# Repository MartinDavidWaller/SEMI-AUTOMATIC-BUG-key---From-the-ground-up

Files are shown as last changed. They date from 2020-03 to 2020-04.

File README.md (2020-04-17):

# SEMI-AUTOMATIC BUG key - From the ground up

The details found here relate to a project published in Practical Wireless. 
It combines a 3d printed [Key](Key.md) and an Arduino based [Keyer](Keyer.md).

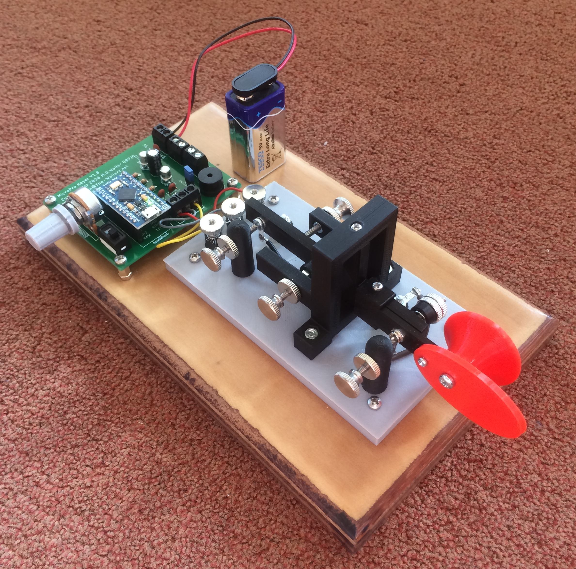
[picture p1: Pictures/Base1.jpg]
 
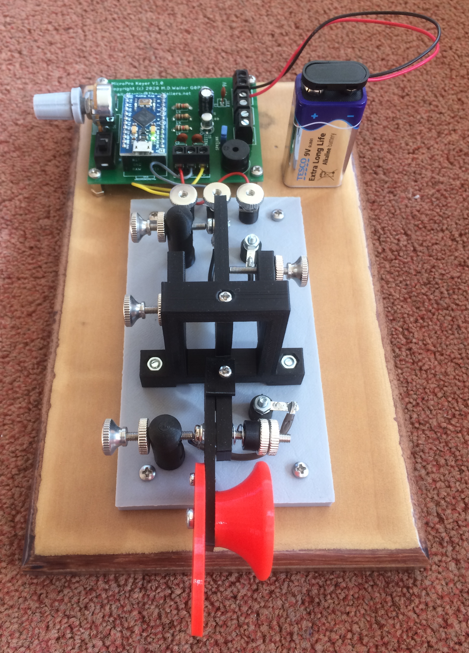
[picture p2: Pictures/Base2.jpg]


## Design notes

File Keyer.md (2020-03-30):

# SEMI-AUTOMATIC "BUG" key - From the ground up

Keyer
 
## Required Components
 
### Resistors
 
| Value | Quantity | Comment |
| --- | --- | --- |
| 1K | 3 | |
| 10K | 1 | |
| Linear Variable 10K | 1 | PCB mountable type |

### Capacitors
 
| Value | Quantity | Comment |
| --- | --- | --- |
| 0.01uF | 3 | |
| 100uF | 1 | Electrolytic, radial lead |

### Semiconductors
 
| Part | Quantity | Comment |
| --- | --- | --- |
| 2N2222 | 2 | |

### Miscellaneous

The URL links provided are not to be seen as any form of promotion, simply as guidance as to what the exact component is.
 
| Part | Quantity | Comment |
| --- | --- | --- |
| 6x6mm Tactile Switch | 1 | Similar to <https://www.bitsbox.co.uk/index.php?main_page=product_info&cPath=116_117_119&products_id=3263> | |
| Miniature PCB slide switch | 1 | Similar to <https://www.bitsbox.co.uk/index.php?main_page=product_info&cPath=116_120_124_125&products_id=870> |
| Miniature Electromagnetic Transducer | 1 | Similar to <https://www.bitsbox.co.uk/index.php?main_page=product_info&cPath=302_309&products_id=2098> |
| 2-Way PCB Terminal Blocks | 3 | Similar to <https://www.bitsbox.co.uk/index.php?main_page=product_info&cPath=225_232&products_id=2962> |
| 3-Way PCB Terminal Blocks | 1 | Similar <https://www.bitsbox.co.uk/index.php?main_page=product_info&cPath=225_232&products_id=1712> | 
| 12-Way SingleRow Socket | 2 | Optional, the Arduino can be soldered to the board. <https://www.bitsbox.co.uk/index.php?main_page=product_info&cPath=225_230&products_id=1643> |
| Arduino Pro Micro | 1 | Similar to <https://www.ebay.co.uk/itm/1-2-5-10PCS-Leonardo-Pro-Micro-ATmega32U4-16MHz-5V-ATmega328-Arduino-Pro-Mini/152216277704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> |
| PCB | 1 | Optional, the keyer can easily be built on Veroboard or similar. |

## Installing the Build Software

Start by installing the Arduino IDE. This can be found at:

https://www.arduino.cc/en/Main/Software

For the purpose of this build the Windows version Arduino 1.8.8 was used. 
All default installation options were accepted.

## Compiling the source code

- This project is based on the K3NG open source keyer and the code can be found here <https://github.com/k3ng/k3ng_cw_keyer>.
At the top right of this page you will see a green button that reads "Clone or download". Click on the small downward arrow and select "Download ZIP". 
Unzip the contents into a folder of your choice.
- To support the chosen hardware a few code changes need to be made. The table below details the file changes. 
It includes the filename, the old code and new code. Sadly line numbers are of little use as the K3NG project is evolving.

### Required Code Changes

The following two changes involve removing the "//" comment lead characters to enable the command button and speed potentiometer.
 
| File | Old Code | New Code |
| --- | --- | --- |
| keyer_features_and_options.h | // #define FEATURE_COMMAND_BUTTONS | #define FEATURE_COMMAND_BUTTONS |
| keyer_features_and_options.h | // #define FEATURE_POTENTIOMETER | #define FEATURE_POTENTIOMETER |

The following change involves changing the trailing 0 to 1 to have the speed potentiometer continually honoured.
 
| File | Old Code | New Code |
| --- | --- | --- |
| keyer_settings.h | #define potentiometer_always_on 0  | #define potentiometer_always_on 1 |

The following change involves changing the trailing 0 to 10 to assign the pin to be used to key the TX.
 
| File | Old Code | New Code |
| --- | --- | --- |
| keyer_pin_settings.h | #define ptt_tx_1 0 | #define ptt_tx_1 10 |

### Optional Code Changes

The following changes are optional. If you feel confident using the paddle, or simply up for a challenge, 
then these options can be changed by using the command button and the correct command as documented in the 
keyer wiki pages. If not so confident then it is probably worth doing the following:

The following change controls the startup keyer mode. It changes it from IAMBIC mode to BUG mode.

| File | Old Code | New Code |
| --- | --- | --- |
| k3ng_keyer.ino | configuration.keyer_mode = IAMBIC_B; | configuration.keyer_mode = BUG; |

The following three changes control the startup keyer speed and the upper and lower bounds of the speed
potentiometer.

| File | Old Code | New Code |
| --- | --- | --- |
| keyer_settings.h | #define initial_speed_wpm 26 | #define initial_speed_wpm 16 |
| keyer_settings.h | #define initial_pot_wpm_low_value 13  | #define initial_pot_wpm_low_value 8 |
| keyer_settings.h | #define initial_pot_wpm_high_value 35 | #define initial_pot_wpm_high_value 20 |

- Open the Arduino IDE and then open the k3ng_keyer.ino project file
- Navigate to Tools > Boards and select "Arduino Leonardo". Some of the Arduino Pro Micro devices seem to be identifying themselves as "LilyPad Arduino USB" devices. If
the one you have claims to be one of these then under Tools > Boards select the "LilyPad Arduino USB" device 
and not "Arduino Leonardo".
- Click the "Verify" button (Round circle with a tick mark in it - top left), if successful you will see something like 
"Sketch uses 20144 bytes (70%) of program storage space. Maximum is 28672 bytes.
Global variables use 825 bytes (32%) of dynamic memory, leaving 1735 bytes for local variables. Maximum is 2560 bytes."
though the number may not be exact.
- Make sure that the Arduino is plugged into your PC. Navigate to Tools > Port and make sure that the correct port is selected. See USB Issues below.
- Click the "Upload" button (Right pointing arrow - top left) to up load the software.
- The device should now be programmed correctly.

## PCB Revisions

- V1.1 - Legend changes.
- V1.0 - March 13th, 2020 - Initial board design.

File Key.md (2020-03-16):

# SEMI-AUTOMATIC "BUG" key - From the ground up

 Key
 
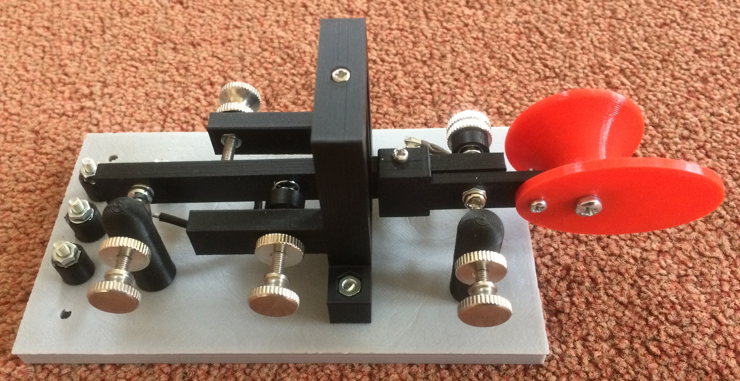
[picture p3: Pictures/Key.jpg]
  
 
 ## Required Parts
 
 The following parts are all 3D printed. The table below details the part, the colour, the infill, 
 and the approximate length of PLA required. If parts seem too 'bendy' then you may like to increase
 the infill percentage when printing.

| Part | Colour | Quantity | Infill % | Total Length |
| --- | ---| ---| --- | --- |
| Base | Grey | 1 | 20% | 8.56m |
| Binding Post	 | Black  | 5 | 20%	 | 0.55m |
| Dah Sprint Cup | Black  | 1 | 20%	 | 0.06m |
| Knob	 | Red | 1 | 20%	 | 1.23m |
| Knob Plate	 | Red | 1 | 20%	 | 0.28m |
| Lever Arm	 | Black  | 1 | 80%	 | 2.25m |
| Main Frame	 | Black  | 1 | 20%	 | 3.81m |
| Short Contact Post | Black  | 2 | 20%	 | 0.74m |
| Spring Cup	 | Black  | 1 | 20%	 | 0.08m |
| Yoke	 | BLack  | 1 | 80%	 | 0.82m |

Total length of PLA required 18.38m

The table below details all the additional hardware, nuts & bolts etc.

| Part | Quantity | See Note |
| --- | ---| --- |
| Compression Spring 7mm x 10mm | 2 | 1 |
| M2 Bolt 6mm | 1 | 2 |
| M2 Bolt 20mm | 3 | 3 |
| M2 Nut | 5 | 2 |
| M3 Bolt 6mm | 1 | 2 |
| M3 Bolt 12mm | 3 | 2 |
| M3 Bolt 16mm | 7 | 2 |
| M3 Bolt 25mm | 1 | 5 |
| M3 Knurled Bolt 20mm | 4 | 4 |
| M3 Knurled Nut | 6 | 4 |
| M3 Nut | 23 | 2 |
| M3 Nylon Washer | 1 | 2 |
| M3 Solder Tag | 15 | 2 |
| M3 Washer | 5 | 2 |

Notes:

1. Bought on ebay as a collection of assorted springs. Looking around you can find vendors selling individual prints. <https://www.ebay.co.uk/itm/Small-Tension-and-Compression-Springs-50-Mixed-Pack-Various-Sizes/362399846579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>
2. Bought from BitsBox. <https://www.bitsbox.co.uk/>
3. Bought on ebay. <https://www.ebay.co.uk/itm/A2-STAINLESS-STEEL-POZI-PAN-HEAD-MACHINE-SCREWS-POZIDRIVE-BOLTS-VARIOUS-SIZES-UK/111302864530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>
4. Bought on ebay. <https://www.ebay.co.uk/itm/Stainless-Steel-Knurled-Thumb-Screws-Hand-Grip-Knob-Bolts-M2-M2-5-M3-M4-M5-M6/283734090984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> <https://www.ebay.co.uk/itm/Carbon-Steel-Leveling-Round-Knurled-Thumb-Nut-Zinc-Ni-Plated-M2-M2-5-M3-M4-M5-M6/283734043425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>
5. Found in my bit box. I'm sure they will be readily found on ebay.

## Assembly

Assembly is quite easy. Below are the steps to follow. The only required tools are a screwdriver and small pliers.

### Step 1

Install 3 binding posts. These provide connections to the keyer. Each post requires:

* M3 Bolt 16mm * 1
* M3 Solder Tag * 1
* Printed Binding Post * 1
* M3 Nut * 2
* M3 Washer * 1

Expect to bury one nut within the body of the binding post. See the images below for the detailed construction. 

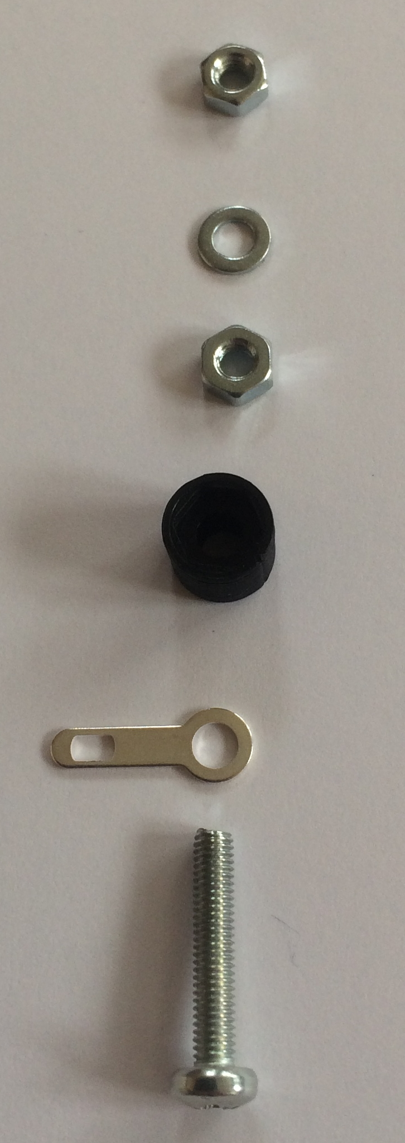
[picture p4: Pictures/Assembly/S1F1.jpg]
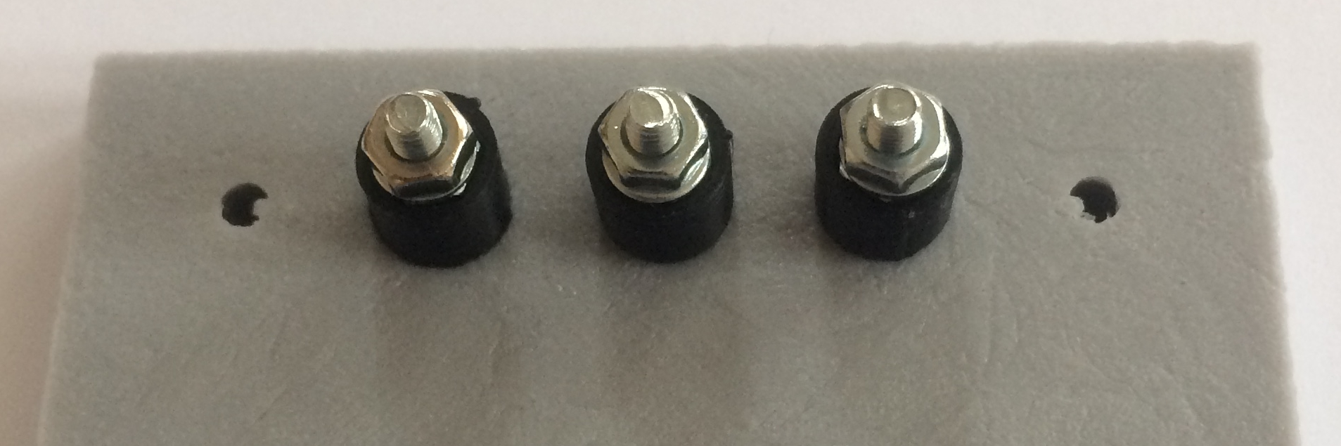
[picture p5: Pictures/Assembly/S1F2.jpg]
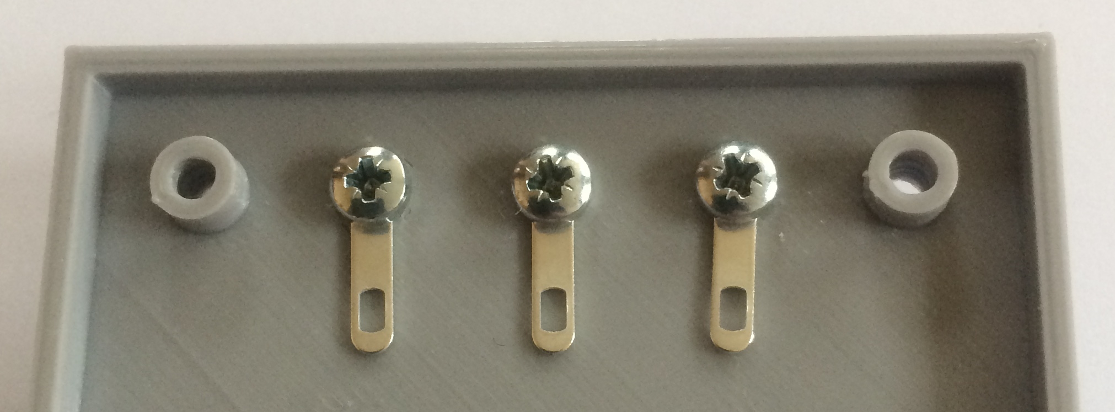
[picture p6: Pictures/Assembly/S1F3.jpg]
  

### Step 2

Install 2 binding posts. These provide connections to the DIT and DAH contacts. Each post requires:

* M3 Bolt 16mm * 1
* M3 Solder Tag * 2
* Printed Binding Post * 1
* M3 Nut * 2
* M3 Washer * 1

These are constructed in the same way as the binding posts in step 1 apart from there being an extra solder tag on the top side
of the board. See the images below for the detailed construction.

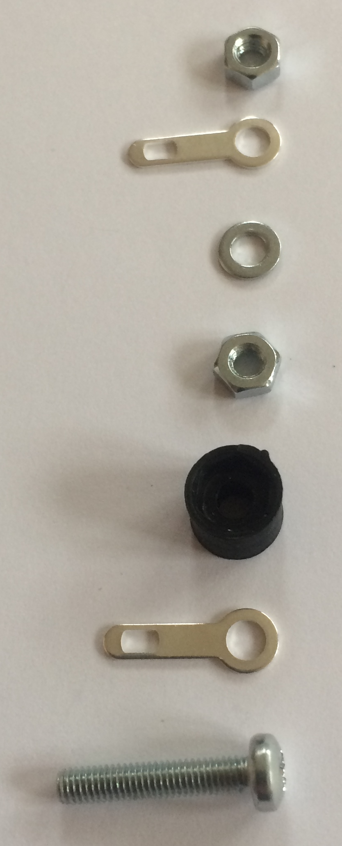
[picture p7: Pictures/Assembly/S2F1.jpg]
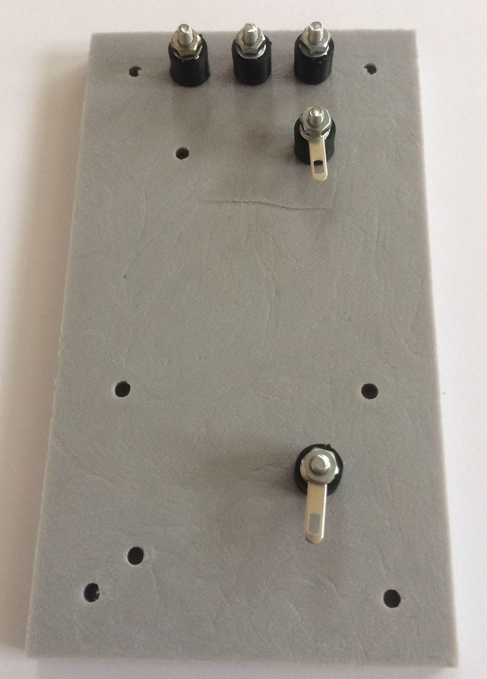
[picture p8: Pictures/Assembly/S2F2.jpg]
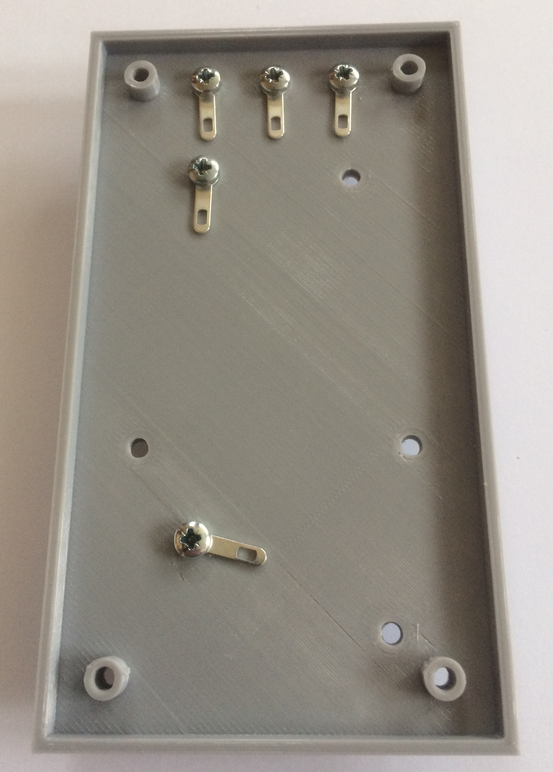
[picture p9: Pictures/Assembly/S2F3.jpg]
  

### Step 3

Install the knob and knob plate on the yoke. This requires:

* M2 Bolt 6mm * 1
* M2 Nut * 1
* M3 Bolt 12mm * 1
* M3 Nut * 1
* Printed Yoke * 1

Start by bolting the knob plate to the yoke using the M2 nut and bolt. The M2 nut should be buried in the yoke itself. 
Insert the M3 nut into the slot in the side of the knob and temporarily insert the M3 bolt in the bottom and screw home. 
This simply ensures that the nut is correctly positioned, remove the bolt. Push the M3 bolt through the knob plate, through
yoke, and into the knob. Position it so that the slot in the knob is pointing downwards and out of sight.
See the images below for the detailed construction.

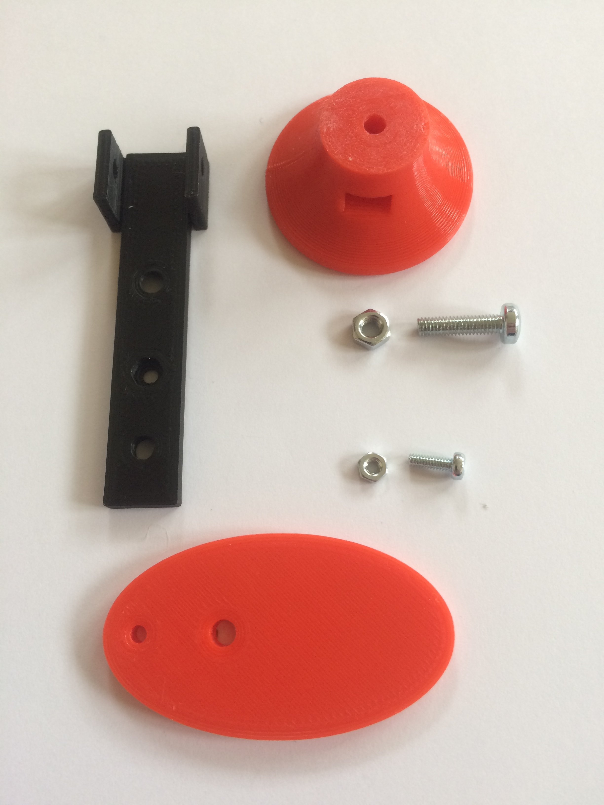
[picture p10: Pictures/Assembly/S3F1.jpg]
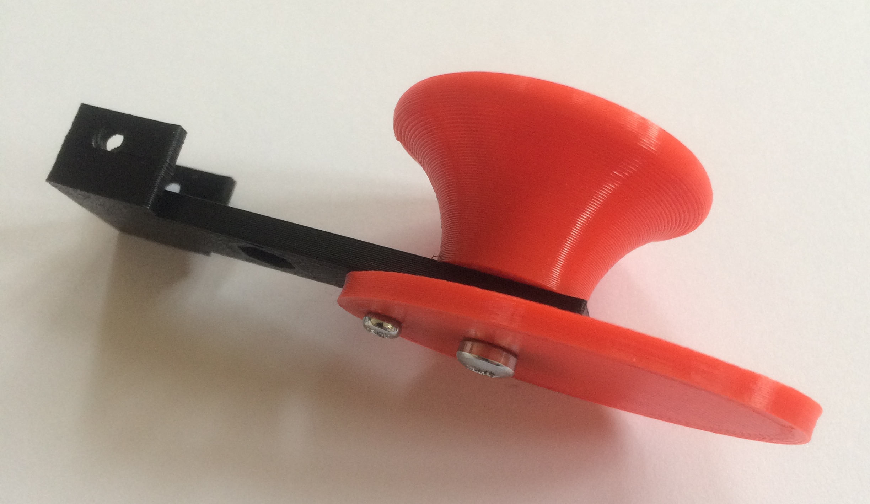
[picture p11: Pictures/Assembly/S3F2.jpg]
 

### Step 4

Install the DIT contact in the lever arm. This requires:

* M3 Bolt 6mm * 1
* M3 Nut * 1
* M3 Solder Tag * 1

Simply insert the bolt through the solder tab and then through the lever arm. The nut is buried in the lever arm itself.
See the images below for the detailed construction.

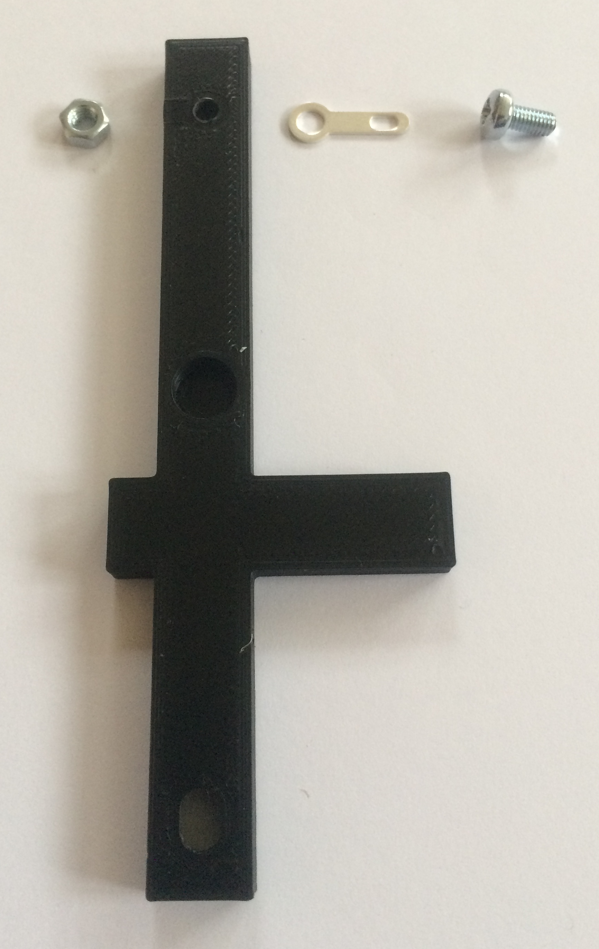
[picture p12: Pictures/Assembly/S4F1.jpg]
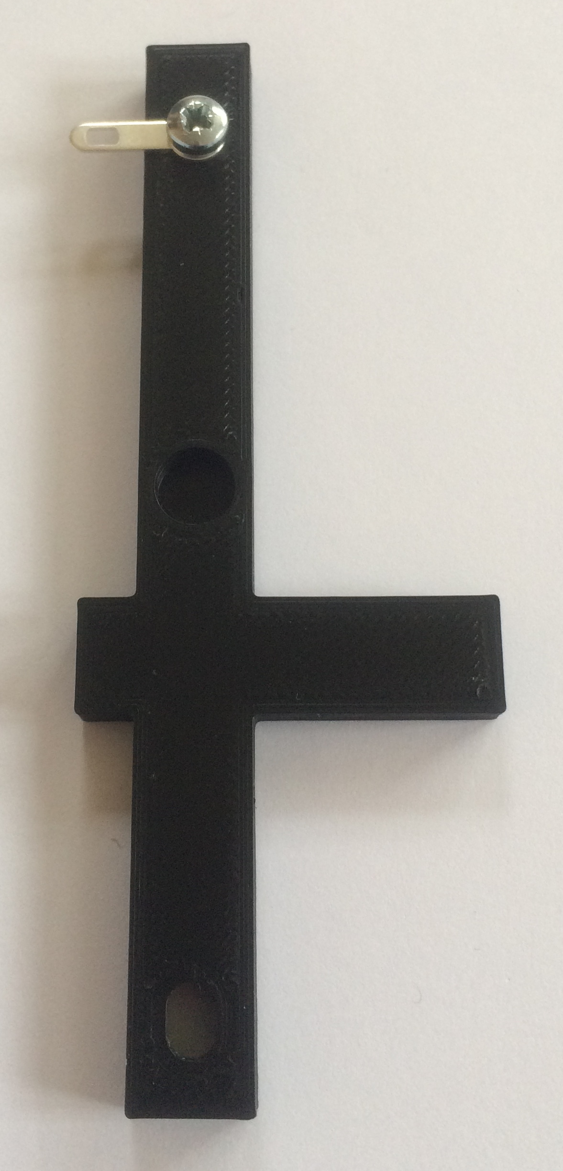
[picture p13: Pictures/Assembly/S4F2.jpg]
 

### Step 5

Assemble the DAH tension sprint. This requires:

* M3 Bolt 25mm * 1
* M3 Solder Tag * 1
* M3 Nut * 1
* M3 Nylon Washer * 1
* Compression Spring 7mm x 10mm * 1
* Assembled Lever Arm * 1
* Printed Dah Sprint Cup * 1
* M3 Knurled Nut * 2

Start by putting the solder tag on the M3 bolt, add the M3 nut and tightened all the way. Hold the lever arm on its side and
place the nylon washer between the yoke and the lever arm so that it aligns with the 3mm hole. Push the bolt through the
hole in the yoke, through the nylon washer and through the lever arm. Place the spring over the bolt followed by the
DAH sprint cup so that it holds the spring secure. Add the two remaining M3 knurled nuts. See the images below for the 
detailed construction.

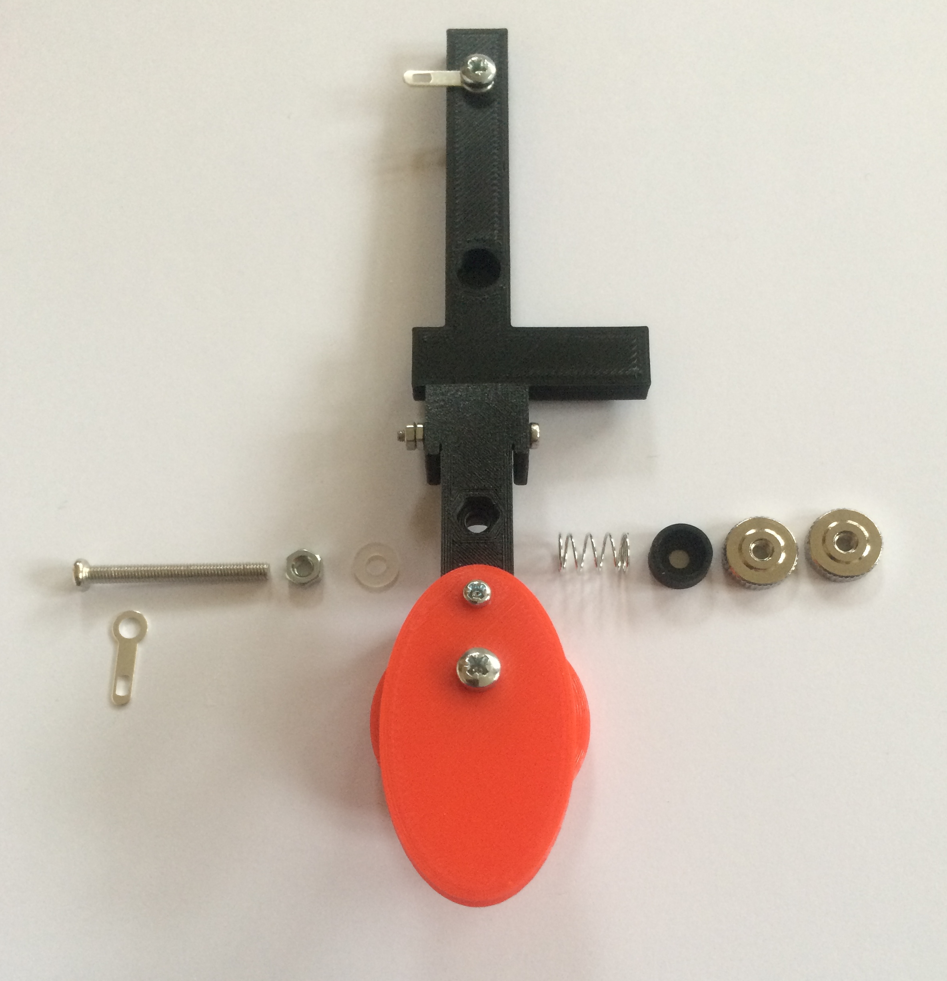
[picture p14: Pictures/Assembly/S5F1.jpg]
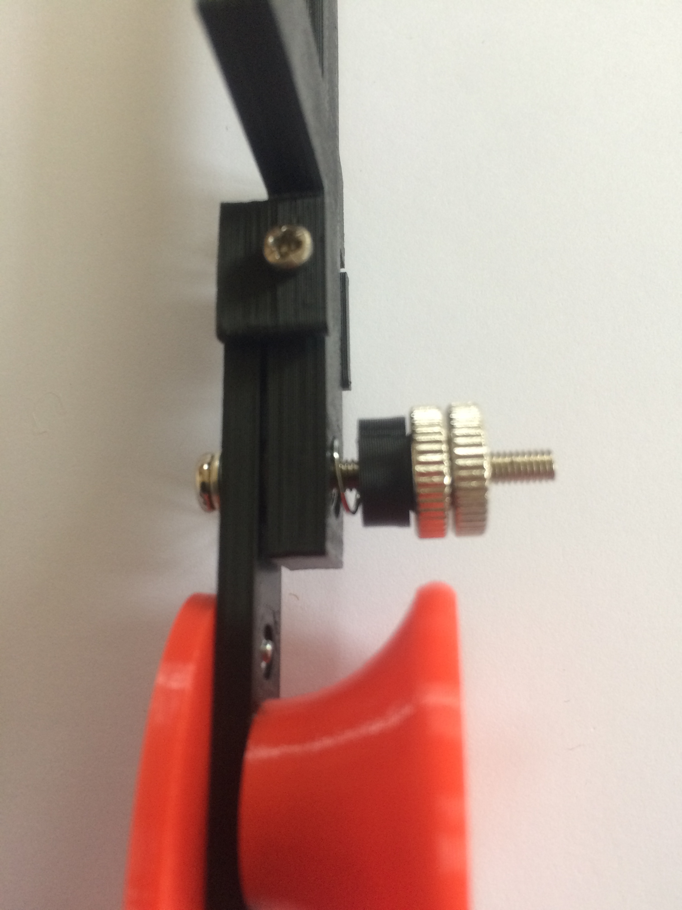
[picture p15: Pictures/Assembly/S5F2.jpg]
 

### Step 6

Assemble the DIT and DAH short contact posts. Each post requires:

* M3 Knurled Bolt 20mm * 1
* M3 Knulred Nut * 1
* M3 Solder Tag * 2
* M3 Nut * 2
* M3 Bolt 16mm * 1
* Printed Short Contact Post * 2

Starting at the top put the knurled nut onto the knurled bolt and screw it all the way down. 
Pass the bolt thought the 3mm hole in the side of the contact post and put one M3 solder 
tag and 3mm nut on the other size and screw home so that the nut is pulled into the contact 
post. At the bottom push the hoop end of a 3mm solder tag into the contact post and above 
that push in a M3 nut. Screw the M3 bolt up through the bottom until it has passed through
the nut. You should then be able to bend the bottom 3mm solder tag over the M3 nut so that 
it makes contact with the upper M3 solder tag. The solder tag can then be soldered together. 
This can be done in situ, but it is best to disassemble and solder them separately.
See the images below for the detailed construction.

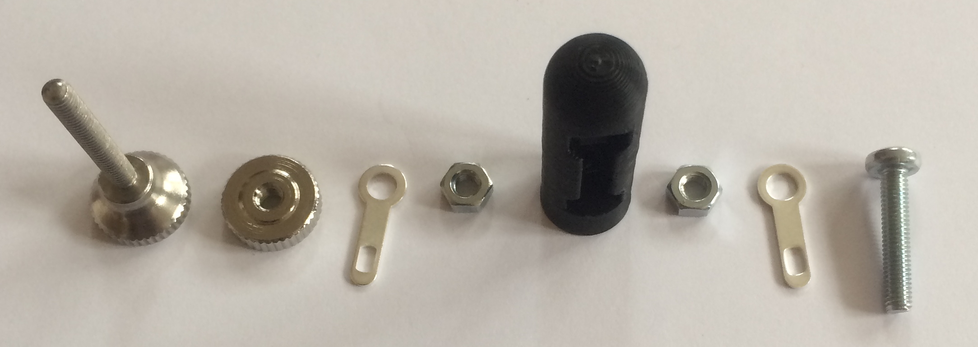
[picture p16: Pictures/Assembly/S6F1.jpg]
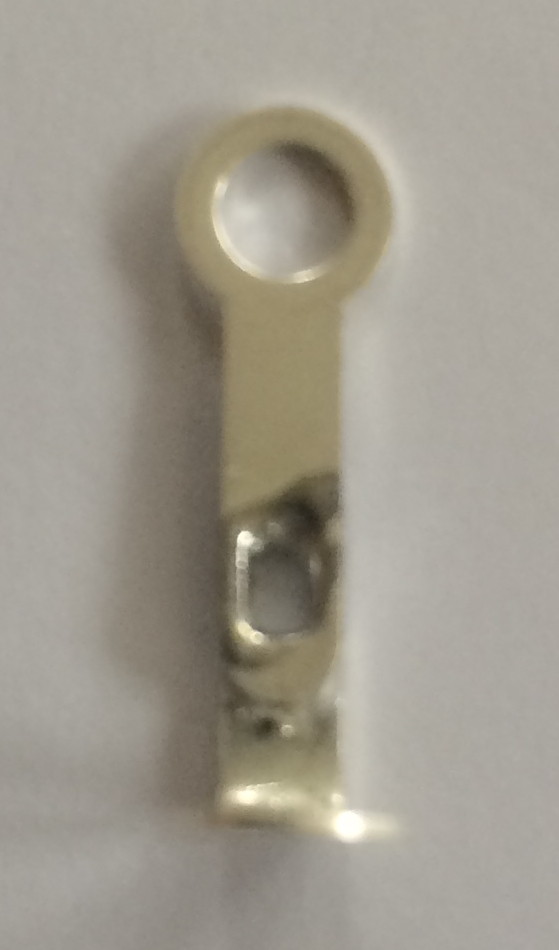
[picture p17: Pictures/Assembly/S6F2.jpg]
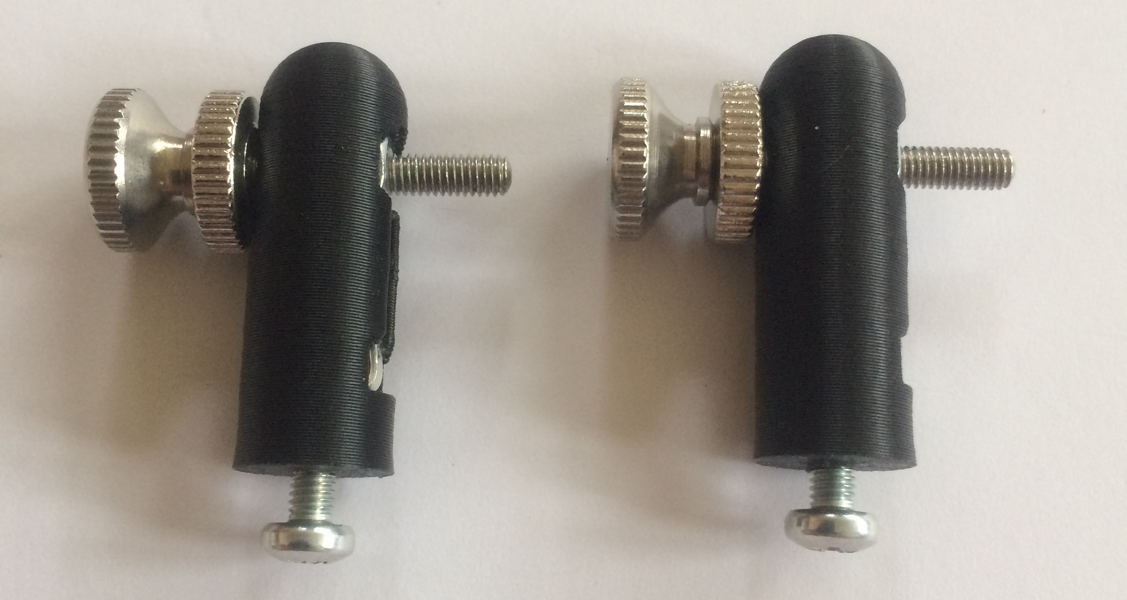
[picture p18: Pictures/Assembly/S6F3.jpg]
  

### Step 7

Assemble the DIT rest. This requires:

* M3 Knurled Bolt 20mm * 1
* M3 Knulred Nut * 1
* Printed Main Frame * 1

Put the 3mm knurled nut on to the 3mm knurled bolt and screw it halfway down. Push the end of the 
3mm bolt through the right-hand arm of the body and add the 3mm nut. Screw this home until the nut is
pulled into the arm. See the images below for the detailed construction.

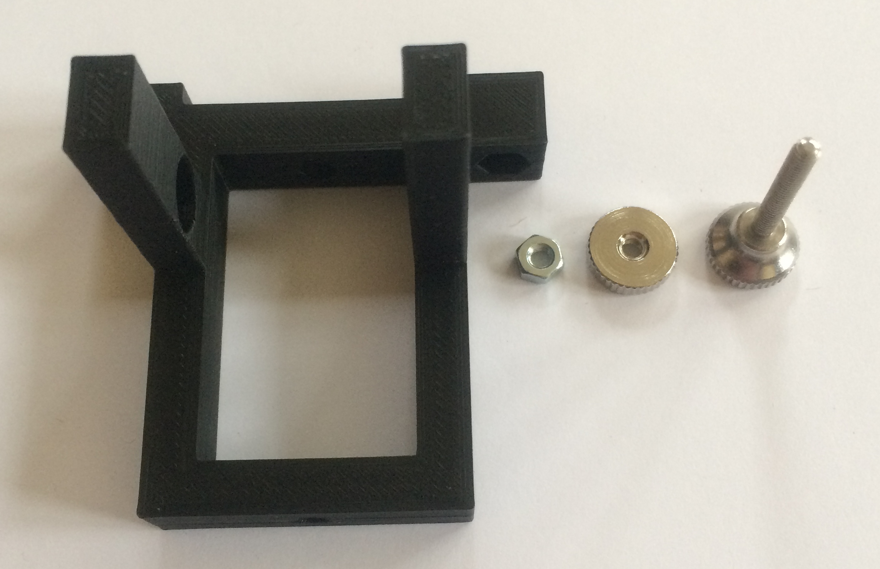
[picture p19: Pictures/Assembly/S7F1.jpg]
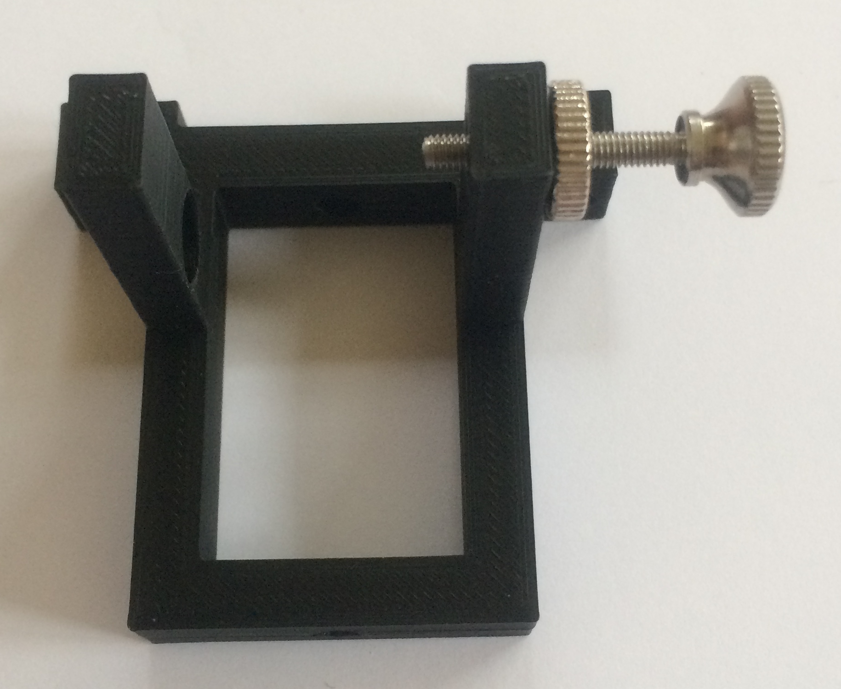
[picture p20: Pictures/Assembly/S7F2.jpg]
 

### Step 8

Assemble the DIT tension. This requires:

* M3 Knurled Bolt 20mm * 1
* M3 Knurled Nut * 1
* M3 Nut * 3
* Printed Spring Cup * 1
* Printed Main Frame * 1

Put the M3 knurled nut on to the M3 knurled bolt and screw it all the way down. Push the end of the 
3mm bolt through the left-hand arm of the body. Add two further M3 nuts, the sprint cup with the 
opening facing to the right, and a further M3 nut. The last two M3 nuts need to be adjusted to hold
the print cup tight at the end of the M3 knurled bolt. The inner M3 nut needs to be pulled into the
arm screwing home the bolt. See the images below for the detailed construction.

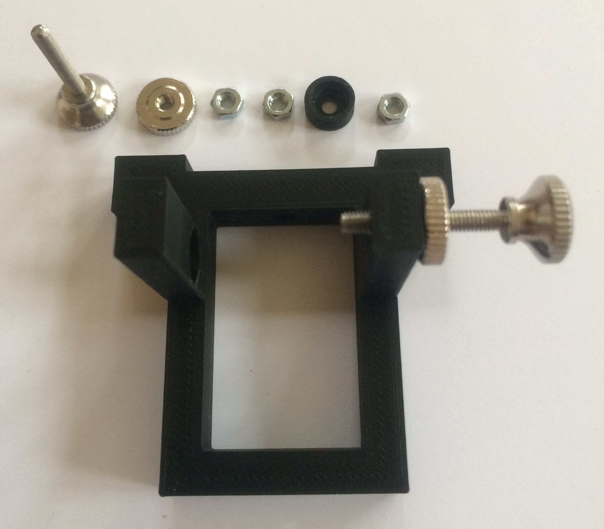
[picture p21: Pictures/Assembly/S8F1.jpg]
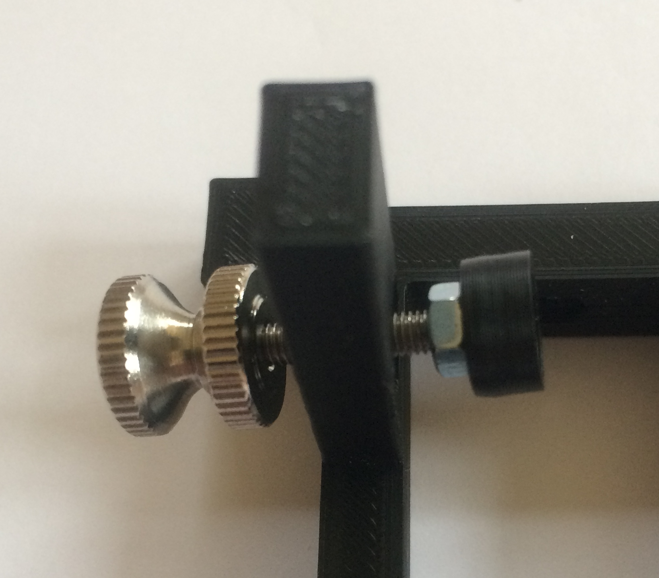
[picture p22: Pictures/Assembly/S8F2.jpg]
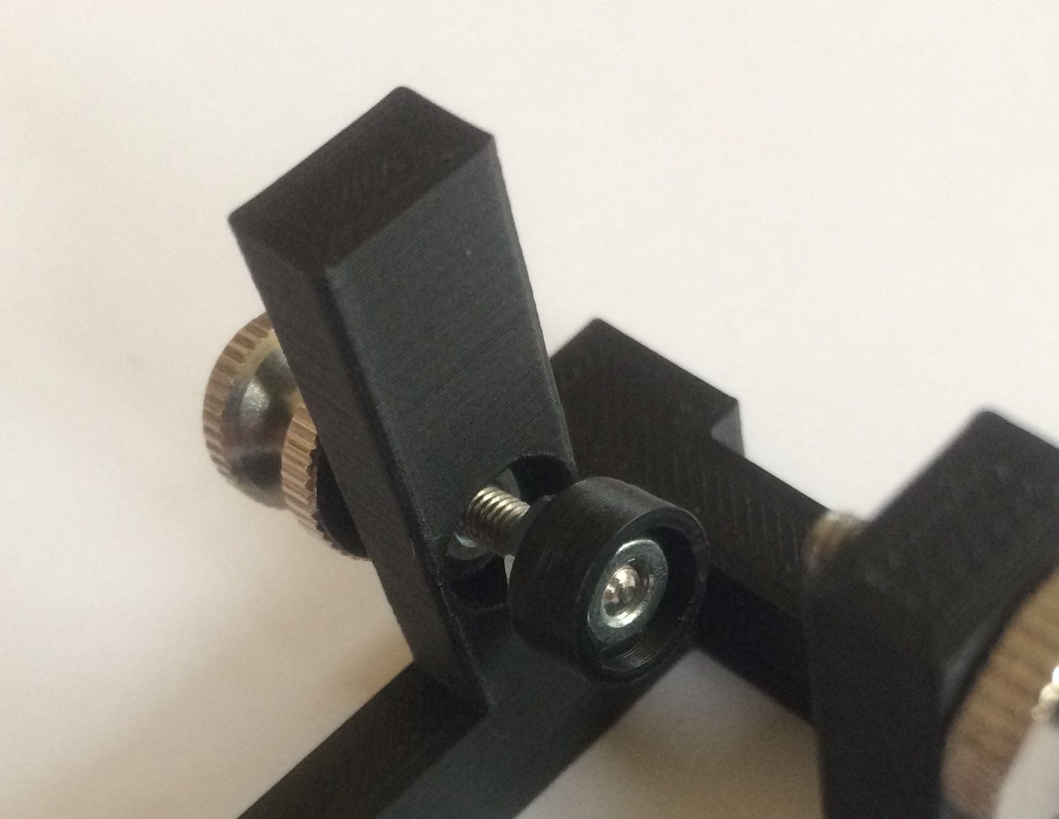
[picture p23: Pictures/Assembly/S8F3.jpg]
  

### Step 9

Secure the assembled lever arm into the body. This requires:

* Assembled lever arm * 1
* M2 Bolt 20mm * 2
* M2 Nut * 2
* Compression Spring 7mm x 10mm * 1
* Printed Main Frame * 1

Start by putting 1 M2 bolt though the top and screwing on a nut so that the thread just pokes though. Repeat this process for the
bottom. Push the assembled lever arm through the main frame until holes in the upright align with the M2 bolts. Screw the M2 bolts
home. This can be fiddly and best done holding the main frame horizontal. Put one end of the compression spring in the spring cup 
and the other end in the recess in the lever arm. You may need to adjust the DIT rest to hold the sprint in place. See the images 
below for the detailed construction.

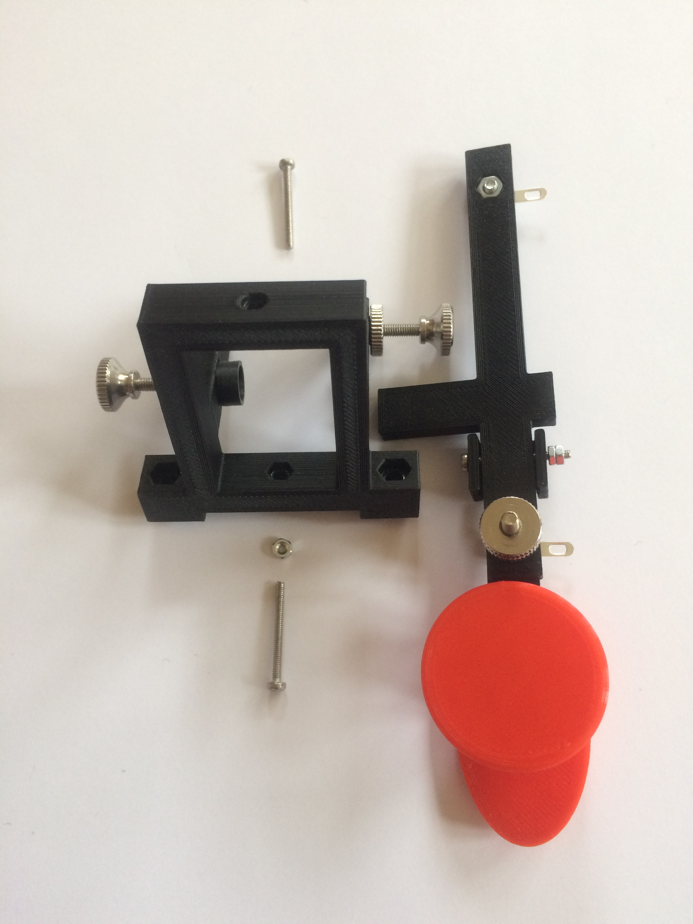
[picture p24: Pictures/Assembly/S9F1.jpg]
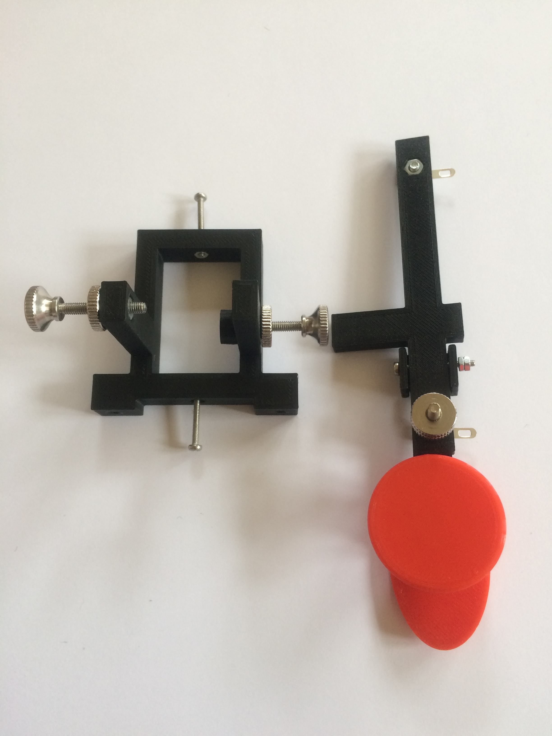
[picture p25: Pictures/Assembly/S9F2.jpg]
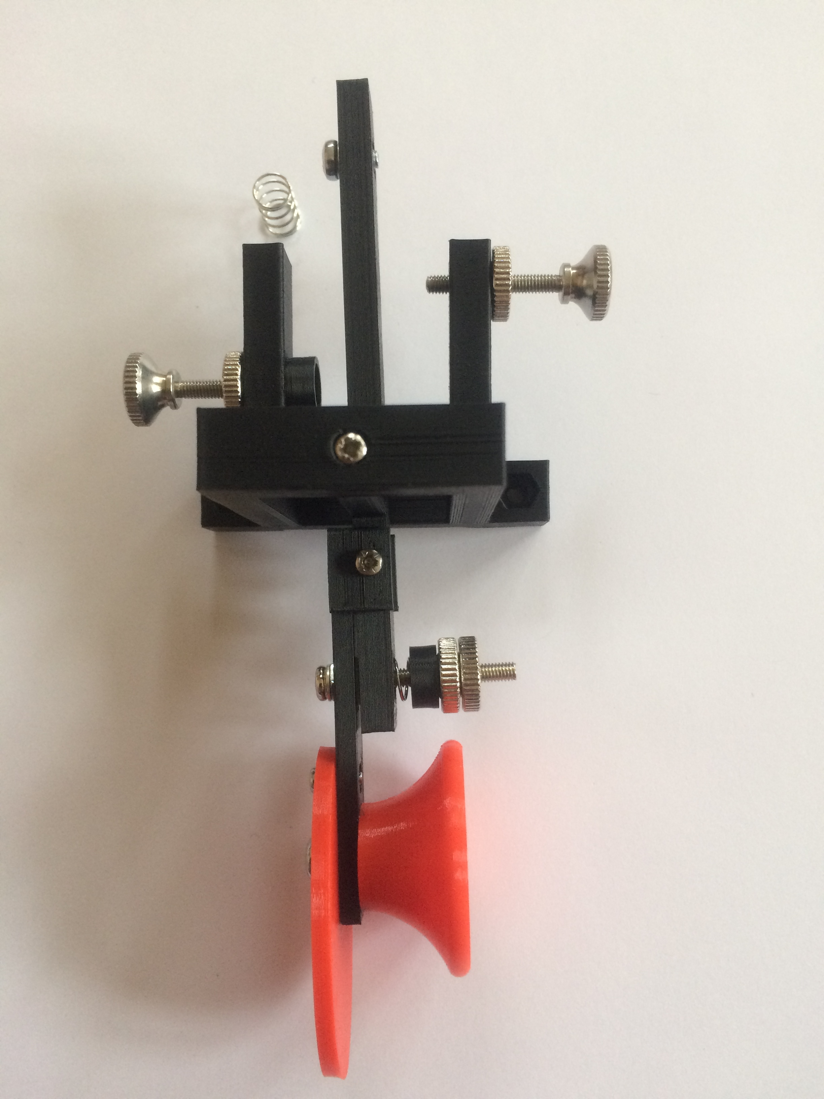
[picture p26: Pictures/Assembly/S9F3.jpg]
     

### Step 10

Secure the main frame to the base. This requires:

* M3 Bolt 16mm * 2
* M3 Nut * 2
* Assembled Base * 1
* Assembled Main Frame * 1

Insert the two M3 bolts up through the base and into the main frame. Add the M3 nuts and secure. See the images 
below for the detailed construction.

  

### Step 11

Secure the DIT and DAH contact posts to the base. This requires:

* M3 Solder Tag * 2
* Assembled Short Contact Post * 2
* Assembled Base * 1

Insert one M3 bolt through an M3 solder tag and then up through the base. Screw into the bottom of a sort contact post. 
Align the contact post with the associated DIT or DAH contact. Repeat for the second short contact post. See the images 
below for the detailed construction.

    

### Step 12

Add hook up wires. This requires:

* Assembled keyer * 1
* Short lengths of hook up wire, preferably multi strand for the top connections.

This is best described by the images below. 



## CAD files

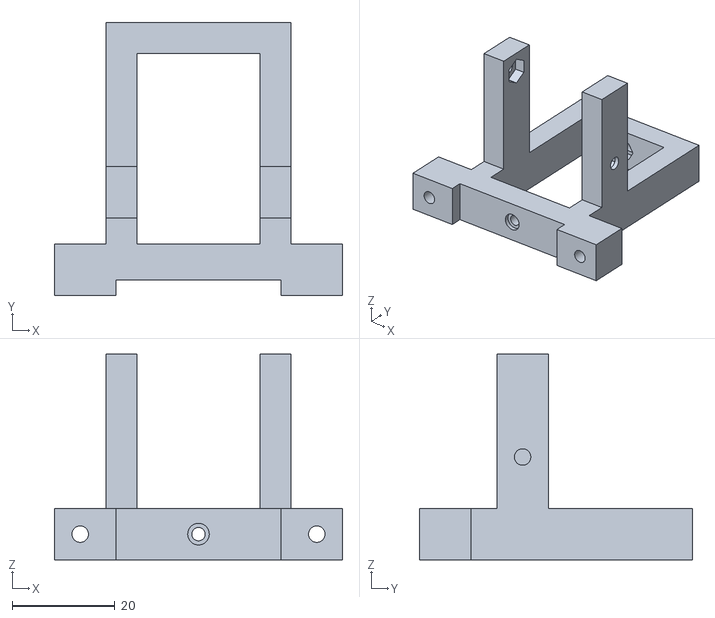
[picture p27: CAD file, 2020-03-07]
STL/MainFrame.stl
56.0 x 53.0 x 40.0

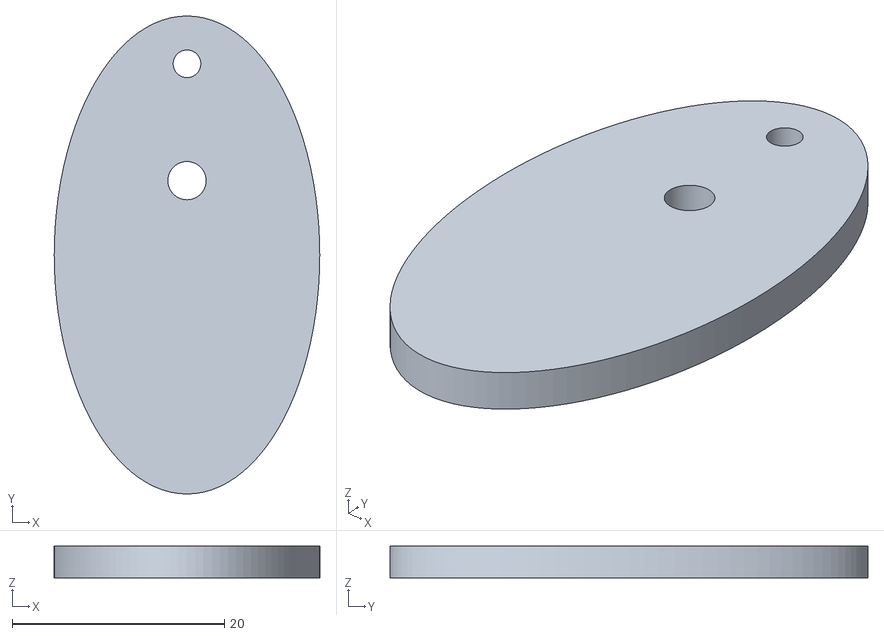
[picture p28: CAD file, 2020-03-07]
STL/KnobPlate.stl
25.0 x 45.0 x 3.00

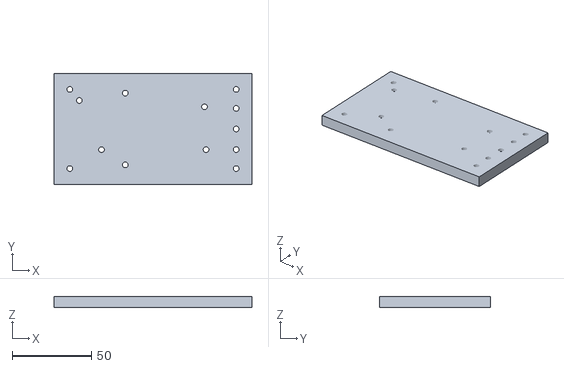
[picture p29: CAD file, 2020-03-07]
STL/Base.stl
125.0 x 70.0 x 7.00

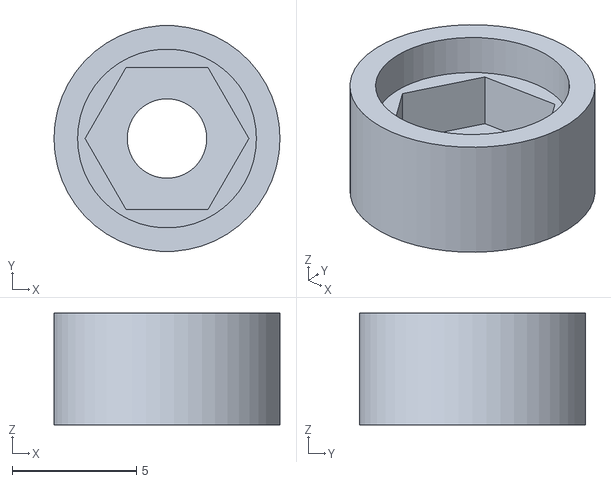
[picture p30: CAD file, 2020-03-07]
STL/SpringCup.stl
9.10 x 9.08 x 4.50

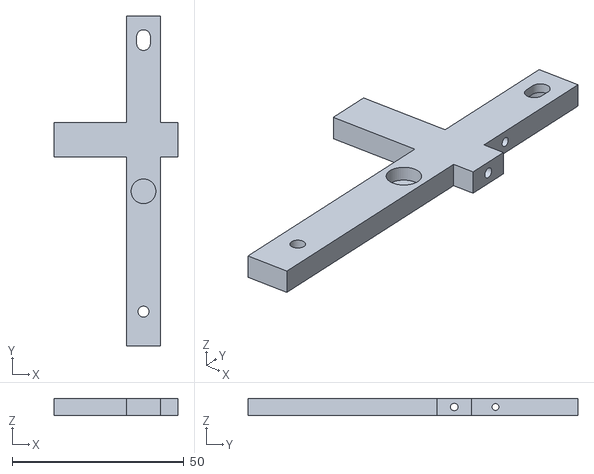
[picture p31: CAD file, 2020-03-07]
STL/LeverArm.stl
36.0 x 96.0 x 5.00

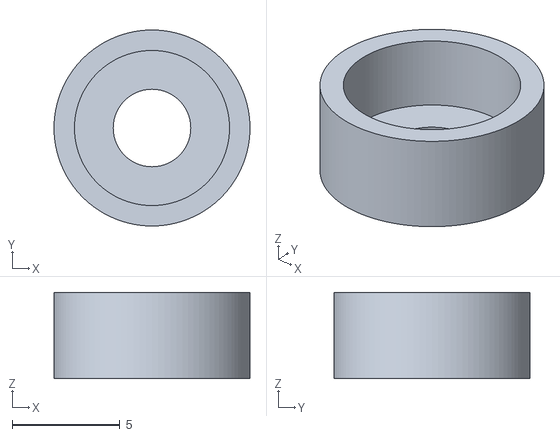
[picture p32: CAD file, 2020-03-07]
STL/DahSpringCup.stl
9.10 x 9.10 x 4.00

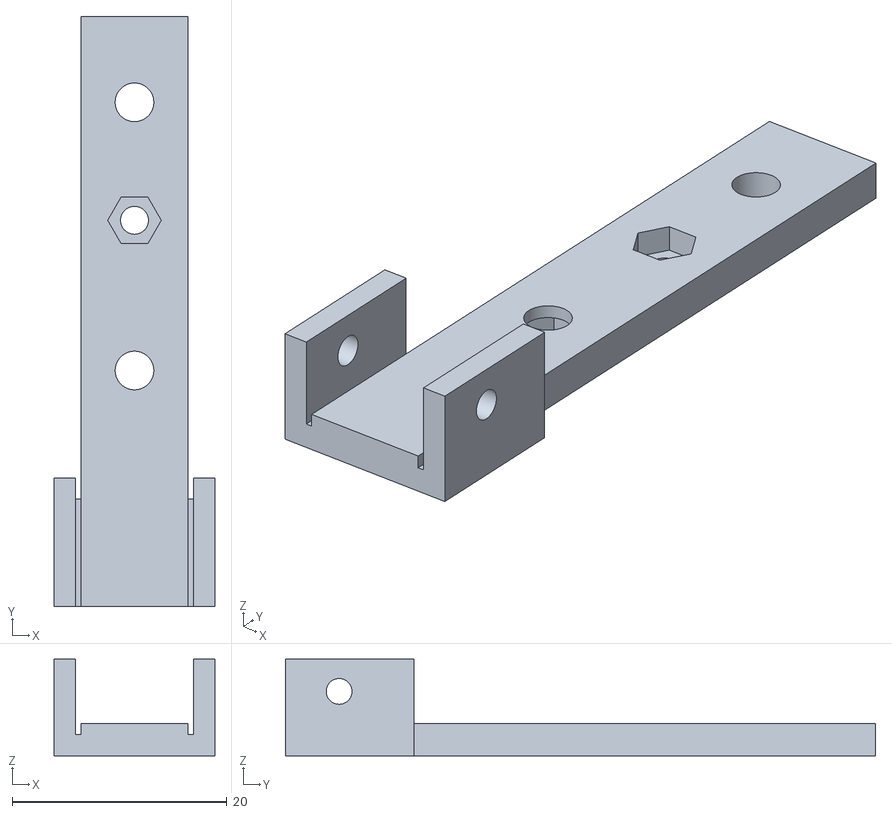
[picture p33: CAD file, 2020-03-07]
STL/Yoke.stl
15.0 x 55.0 x 9.00

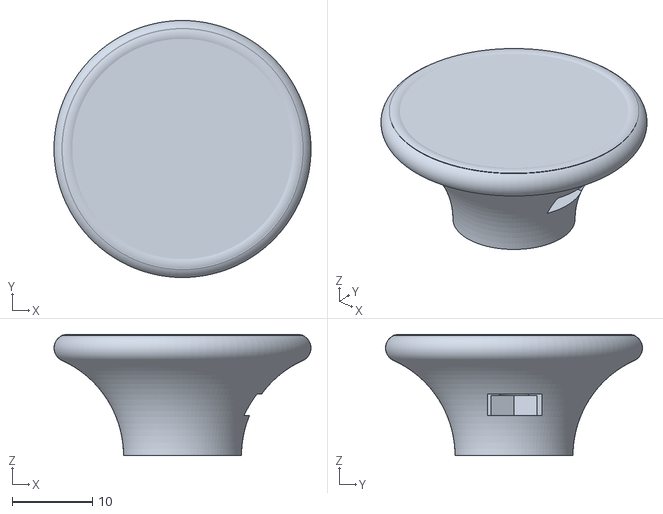
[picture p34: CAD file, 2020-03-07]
STL/Knob.stl
32.0 x 32.0 x 15.1

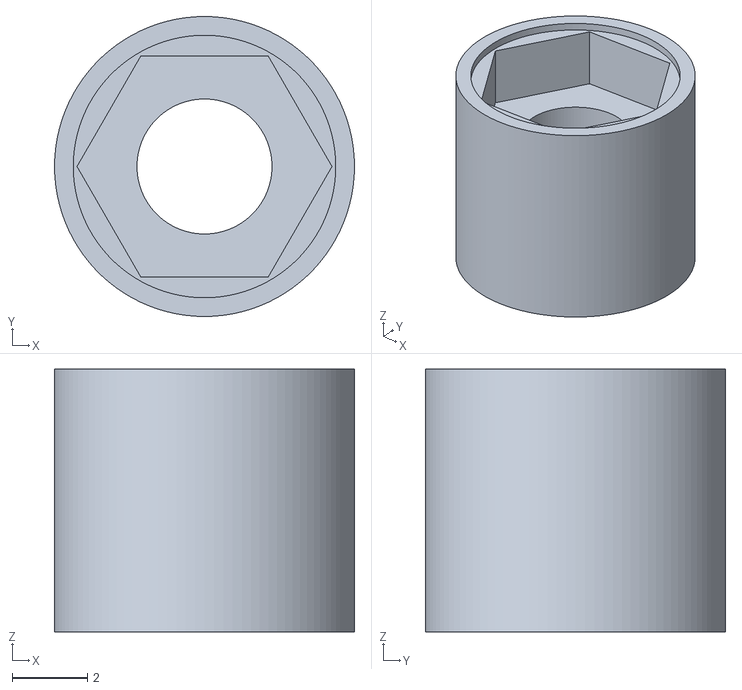
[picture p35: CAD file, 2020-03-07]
STL/BindingPost.stl
8.00 x 8.00 x 7.00

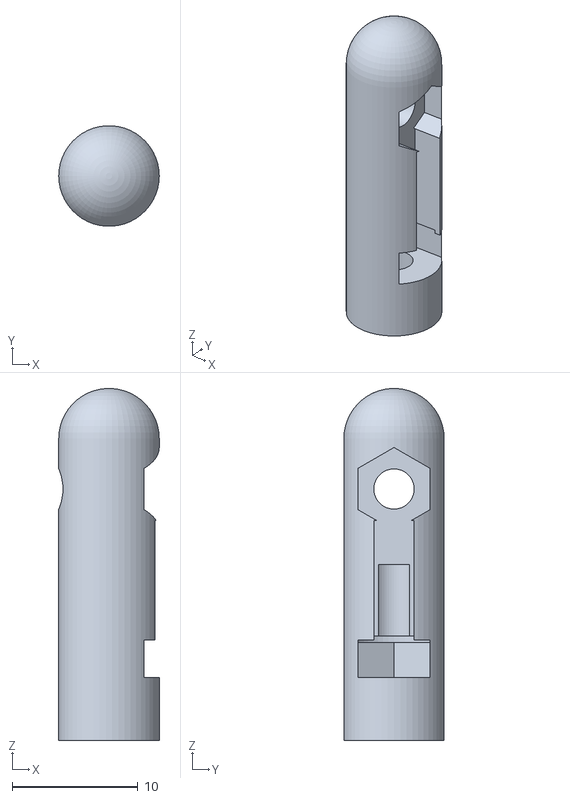
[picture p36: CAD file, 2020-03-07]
STL/ShortContactPost.stl
8.00 x 7.98 x 28.0

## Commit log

2020-03-07 ReadME update
    See above
    [Base.stl, BindingPost.stl, DahSpringCup.stl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]
2020-03-31 Added more files
    Added pictures and the PCB files.
    [ProMicro Keyer - V1_1.brd]
